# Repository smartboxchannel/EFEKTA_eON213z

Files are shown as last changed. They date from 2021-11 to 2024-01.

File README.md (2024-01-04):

# EFEKTA_eON213z

Телеграм чат DIY Devices - https://t.me/diy_devices

Продажа DIY Устройств - https://t.me/diydevmart

My new zigbee project. Wireless temperature and humidity mini sensor with electronic ink display 2.13 inches, low power consumption, compact size, enclosure with magnets. The device use SHTC3 sensors, chip CC2530, battery CR2477. Support in zigbee2mqtt, zha.

### It is forbidden to manufacture devices for commercial sale, only for personal use.

### You can buy a ready-made device by writing to the mail hello@efektalab.com

### Delivery is carried out worldwide.

## You can make your own pcb here - https://www.pcbway.com/setinvite.aspx?inviteid=550959

#### Sale: 

#### Video: https://youtu.be/5huTVfVpZgs

#### zigbee2mqtt.io/supported-devices: https://www.zigbee2mqtt.io/supported-devices/#s=efekta

#### Telegram DiyDev - https://t.me/diy_devices

More info at http://efektalab.com/eON213z

Chinese version - https://github.com/wzqvip/EFEKTA_eON213z/tree/Chinese_version

## V1_R1

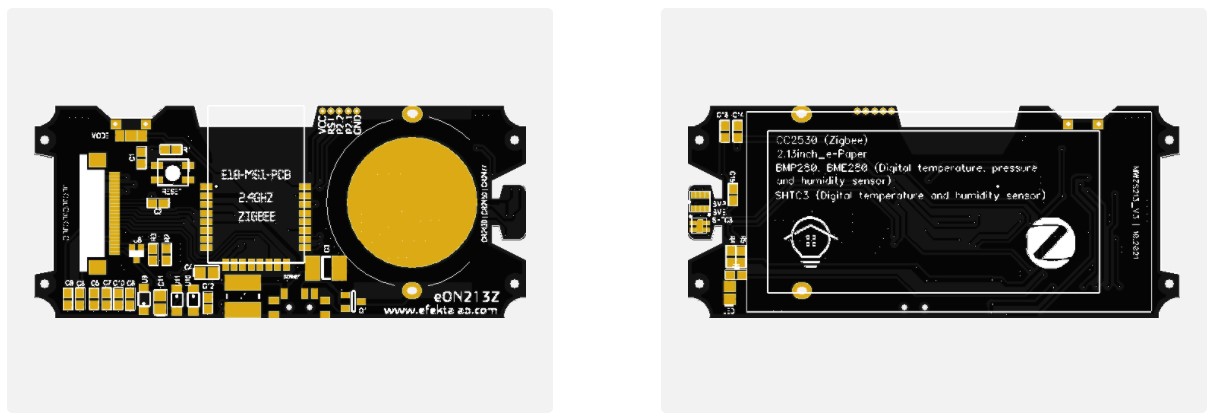
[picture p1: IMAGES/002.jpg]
 

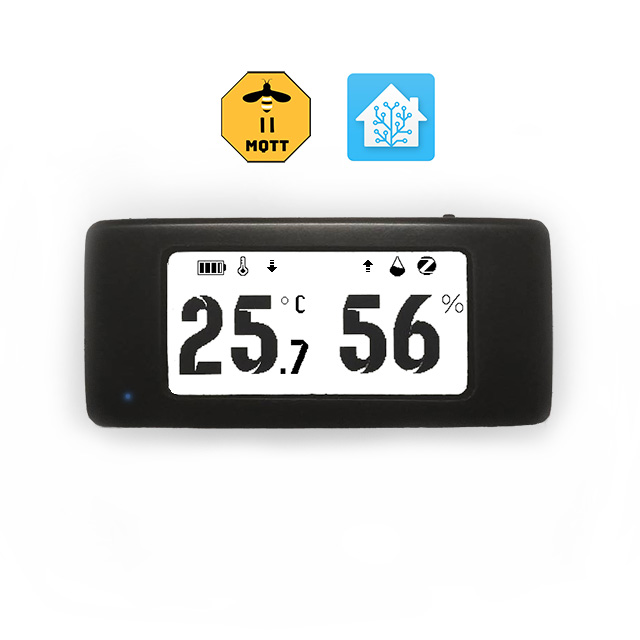
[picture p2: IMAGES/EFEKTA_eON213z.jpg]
Indoor climate sensor EFEKTA eON213 Zigbee
 

### How to flash the device

1. Download the Smart RF Flash Programmer V1 https://www.ti.com/tool/FLASH-PROGRAMMER

2. Open the application select the HEX firmware file

3. Connect the device with wires to CCDebugger, first erase the chip, then flash it.

---

### How to install IAR

https://github.com/ZigDevWiki/zigdevwiki.github.io/blob/main/docs/Begin/IAR_install.md

https://github.com/sigma7i/zigbee-wiki/wiki/zigbee-firmware-install (RU)

---

### How to join:
#### If device in FN(factory new) state:
##### one way
1. Open z2m, make sure that joining is prohibited
2. Insert the battery into the device
3. Click on the icon in z2m - allow joining (you have 180 seconds to add the device)
4. Go to the LOGS tab
5. Press the reset button on the device (the join procedure will begin, еhe device starts flashing the LED repeatedly)
6. Wait, in case of successfull join, device will flash led 5 times, if join failed, device will flash led 2 times

##### another way
1. Open z2m, make sure that joining is prohibited
2. Insert the battery into the device
3. Click on the icon in z2m - allow joining (you have 180 seconds to add the device)
4. Go to the LOGS tab
5. Press and hold button (1) for 2-3 seconds, until device start flashing the LED repeatedly
6. Wait, in case of successfull join, device will flash led 5 times, if join failed, device will flash led 2 times

#### If device in a network:
##### one way 
1. Hold button (1) for 10 seconds, this will reset device to FN(factory new) status 
2. Click on the icon in z2m - allow joining (you have 180 seconds to add the device)
3. Go to the LOGS tab
5. Press and hold button (1) for 2-3 seconds, until device start flashing the LED repeatedly
6. Wait, in case of successfull join, device will flash led 5 times, if join failed, device will flash led 2 times

##### another way
1.Find the device in the list of z2m devices and delete it by applying force remove
2. Click on the icon in z2m - allow joining (you have 180 seconds to add the device)
3. Go to the LOGS tab
4. Press the reset button on the device (the join procedure will begin, еhe device starts flashing the LED repeatedly)
5. Wait, in case of successfull join, device will flash led 5 times, if join failed, device will flash led 2 times

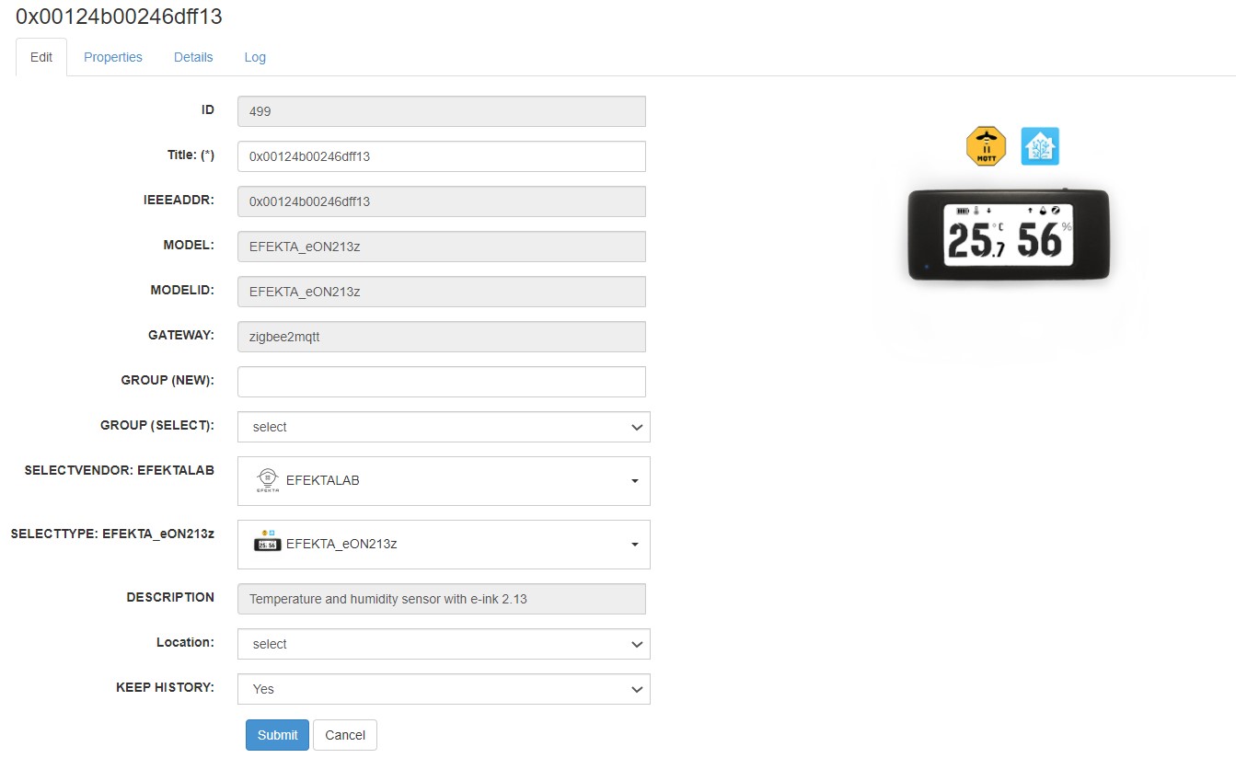
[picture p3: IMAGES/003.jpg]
Efekta THP_LR \ THP
 

### Troubleshooting

If a device does not connect to your coordinator, please try the following:

1. Power off all routers in your network.
2. Move the device near to your coordinator (about 1 meter).
or if you cannot disable routers (for example, internal switches), you may try the following:
2.1. Disconnect an external antenna from your coordinator.
2.2. Move a device to your coordinator closely (1-3 centimeters).
3. Power on, power on the device.
4. Restart your coordinator (for example, restart Zigbee2MQTT if you use it).

If the device has not fully passed the join

1. If the device is visible in the list of z2m devices, remove it by applying force remove
2. Restart your coordinator (for example, restart Zigbee2MQTT if you use it).
3. Click on the icon in z2m - allow joining (you have 180 seconds to add the device)
4. Go to the LOGS tab
5. Press and hold button (1) for 2-3 seconds, until device start flashing the LED repeatedly
6. Wait, in case of successfull join, device will flash led 5 times, if join failed, device will flash led 2 times

### Other checks

Please, ensure the following:

1. Your power source is OK (a battery has more than 3V). You can temporarily use an external power source for testings (for example, from a debugger).
2. The RF part of your E18 board works. You can upload another firmware to it and try to pair it with your coordinator. Or you may use another coordinator and build a separate Zigbee network for testing.
3. Your coordinator has free slots for direct connections.
4. You permit joining on your coordinator.
5. Your device did not join to other opened Zigbee network. When you press and hold the button, it should flash every 3-4 seconds. It means that the device in the joining state.

## Components (BOM):

CC2530 - https://ali.ski/x1m0vF (1 pc - $2.75)

CC2530 - https://ali.ski/mjth48 (10 pcs)

SHTC3 - https://ali.ski/yBYSsV (10 pcs - $15.76)

Waveshare 250x122 2,13 - https://ali.ski/D4eOVU (1pc - $13.3)

FPC FFC 0.5mm connector socket 24 pin - https://ali.ski/lCBot0 (1 p - $0.77)

Cell Holder CR2477 - https://ali.ski/CTUHOc (20 pcs - $5)

Micro Screws M1.4 3mm - https://ali.ski/gaFdO (100 pcs - $1)

Micro Screws M1.4 5mm - https://ali.ski/gaFdO (100 pcs - $1)

Micro SMD Tact Switch 2x4 2*4*3.5 - https://ali.ski/_D78Q (10 pcs - $1)

Neodymium magnet 15x3x3m - https://ali.ski/44p3R (10 pcs - $7)

Tantalum Capacitor 220UF 10V - https://ali.ski/Lx9iQd (10 pcs - $1,85)

Inductor Power Shielded Wirewound NR5040 5x5x4mm - https://ali.ski/iblu8q (50 pcs - $3)

Micro Button Tact Switch SMD 4Pin 3X4X2.5 - https://ali.ski/sGwFu (100 pcs - $1.7)

SMD Mini Toggle Slide Switch 7-Pin On/Off - https://ali.ski/xz9Yt (100 pcs - $3.2)

SI1308EDL - https://ali.ski/Q6Y12 (20 pcs - $5.3)
OR
Si1304BDL - https://ali.ski/938Klh (100 pcs - $15.5)

SMD Chip Multilayer Ceramic Capacitor 0603 1UF 25V - https://ali.ski/p3yr60 (100 pcs - $1.5)

SMD Chip Multilayer Ceramic Capacitor 0603 0.1UF 50V - https://ali.ski/p3yr60 (100 pcs - $1.5)

SMD Chip Multilayer Ceramic Capacitor 0805 4.7UF - https://ali.ski/iFXAc (100 pcs - $1.85)

MBR0530T1G - https://ali.ski/SJM7aK (100 pcs - $1.1)

SMD LED 0805 - https://ali.ski/wb6ZP (100 pcs - $2)

1% SMD resistor 0.47R 0603 - https://ali.ski/bX9HUg (100 pcs - $1.2)

1% SMD Resistor Kit Assorted Kit 1R-1M 0603 -  https://ali.ski/npItF (660 pcs - $1.45)

SUNLU PLA Carbon Fiber Premium 3D Printer Filament - https://ali.ski/bQkNR (1 pcs - $26.5)

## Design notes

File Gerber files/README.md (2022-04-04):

You can make your own pcb here - https://www.pcbway.com/setinvite.aspx?inviteid=550959

pcb 1mm - https://www.pcbway.com/project/shareproject/EFEKTA_eON213z_2ad692dc.html

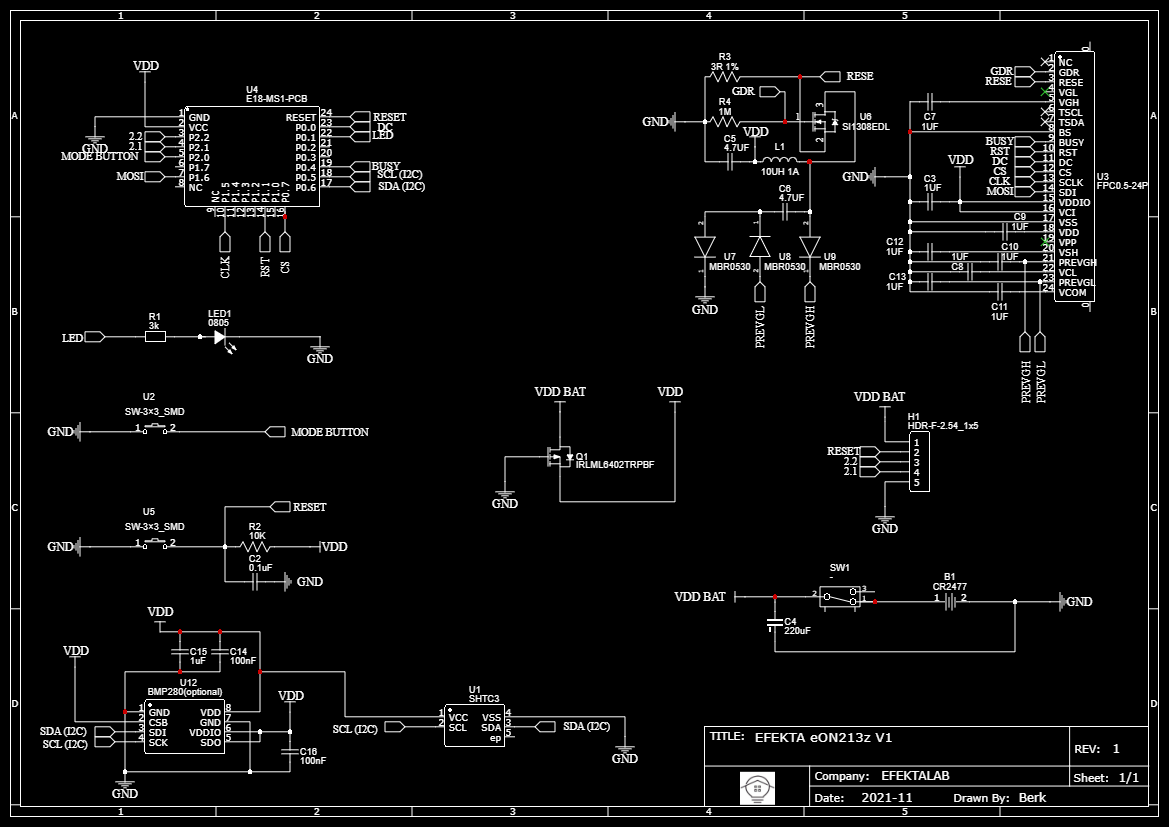
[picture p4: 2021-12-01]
SCHEME/Schematic_EFEKTA_eON213z.png

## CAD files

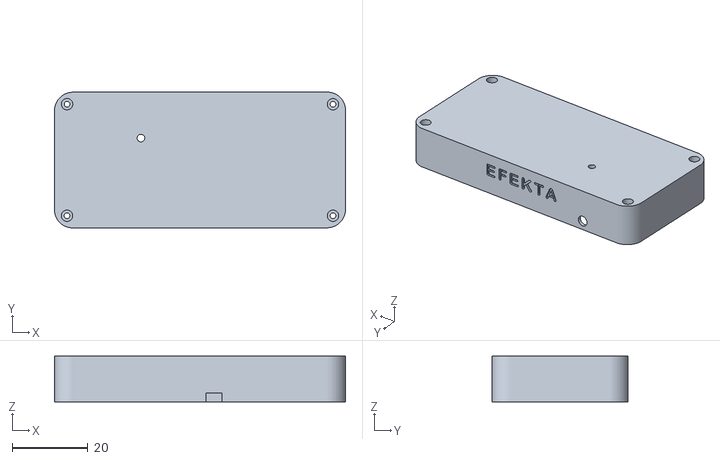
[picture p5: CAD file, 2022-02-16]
ENCLOSURE/thz2477_2.STL
76.6 x 35.7 x 12.1

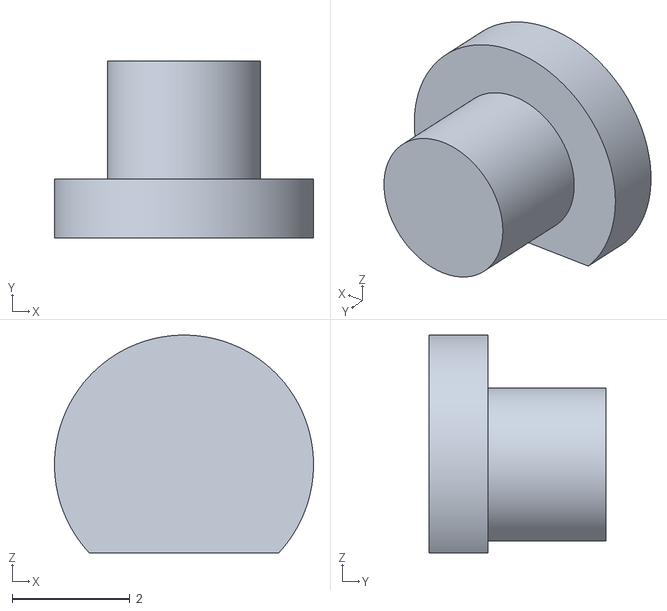
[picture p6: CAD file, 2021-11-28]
ENCLOSURE/thz2477_3.STL
4.40 x 3.00 x 3.70

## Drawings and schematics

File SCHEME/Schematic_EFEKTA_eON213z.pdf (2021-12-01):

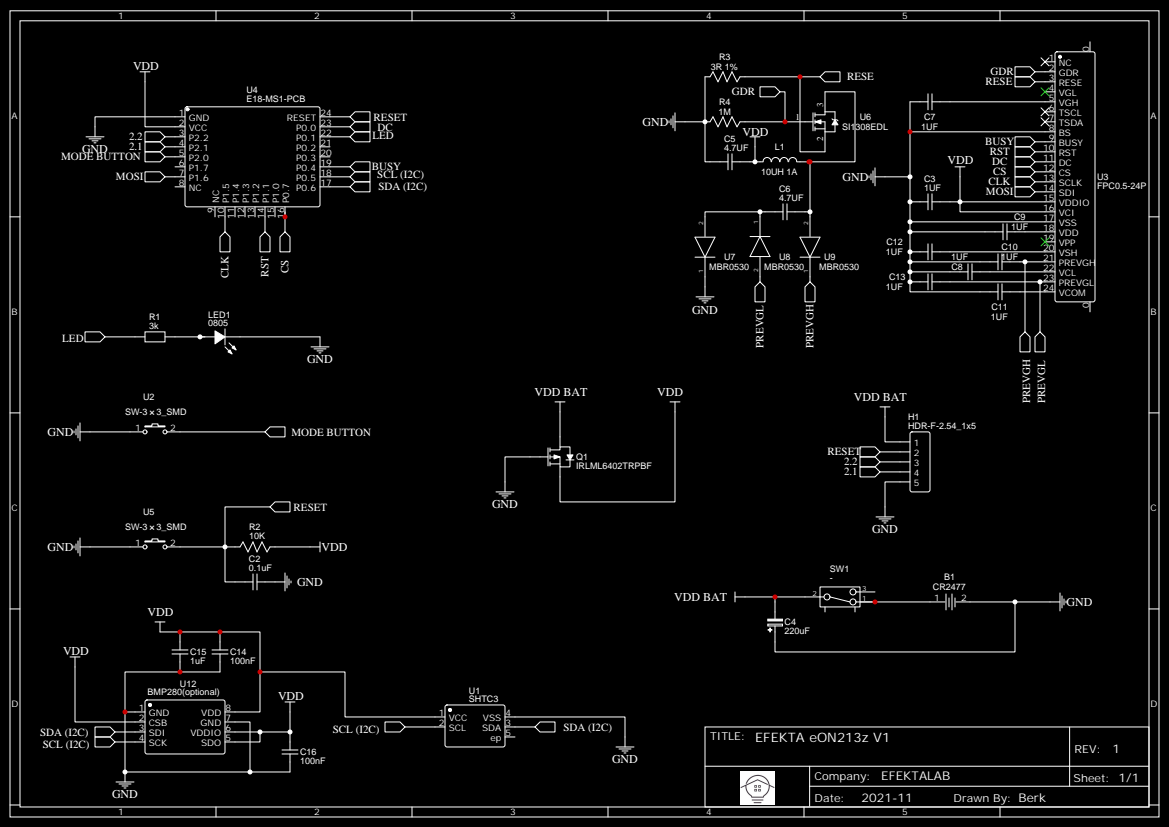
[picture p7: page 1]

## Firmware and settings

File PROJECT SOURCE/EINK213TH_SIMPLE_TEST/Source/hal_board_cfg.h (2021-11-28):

#ifndef HAL_BOARD_CFG_H
#define HAL_BOARD_CFG_H


/* ------------------------------------------------------------------------------------------------
 *                                           Includes
 * ------------------------------------------------------------------------------------------------
 */

#include "hal_mcu.h"
#include "hal_defs.h"
#include "hal_types.h"







/* ------------------------------------------------------------------------------------------------
 *                                          Clock Speed
 * ------------------------------------------------------------------------------------------------
 */

#define HAL_CPU_CLOCK_MHZ     32

/* 32 kHz clock source select in CLKCONCMD */
#if !defined (OSC32K_CRYSTAL_INSTALLED) || (defined (OSC32K_CRYSTAL_INSTALLED) && (OSC32K_CRYSTAL_INSTALLED == TRUE))
#define OSC_32KHZ  0x00 /* external 32 KHz xosc */
#else
#define OSC_32KHZ  0x80 /* internal 32 KHz rcosc */
#endif

#define HAL_CLOCK_STABLE() 

/* ------------------------------------------------------------------------------------------------
 *                                         Key Release detect support
 * ------------------------------------------------------------------------------------------------
 */
#define HAL_KEY_CODE_NOKEY 0xff


/* ------------------------------------------------------------------------------------------------
 *                                       LED Configuration
 * ------------------------------------------------------------------------------------------------
 */

// TODO: review all HAL_BOARD_CC2530EB_REV17 and replace with HAL_BOARD_CC2530RC
//       if applicable.
#define HAL_NUM_LEDS            0

#define HAL_LED_BLINK_DELAY()   st( { volatile uint32 i; for (i=0; i<0x5800; i++) { }; } )
#define ACTIVE_LOW        !
#define ACTIVE_HIGH       !!    /* double negation forces result to be '1' */

/* ------------------------------------------------------------------------------------------------
 *                         OSAL NV implemented by internal flash pages.
 * ------------------------------------------------------------------------------------------------
 */

// Flash is partitioned into 8 banks of 32 KB or 16 pages.
#define HAL_FLASH_PAGE_PER_BANK    16
// Flash is constructed of 128 pages of 2 KB.
#define HAL_FLASH_PAGE_SIZE        2048
#define HAL_FLASH_WORD_SIZE        4

// CODE banks get mapped into the XDATA range 8000-FFFF.
#define HAL_FLASH_PAGE_MAP         0x8000

// The last 16 bytes of the last available page are reserved for flash lock bits.
// NV page definitions must coincide with segment declaration in project *.xcl file.
#if defined NON_BANKED
#define HAL_FLASH_LOCK_BITS        16
#define HAL_NV_PAGE_END            30
#define HAL_NV_PAGE_CNT            2
#else
#define HAL_FLASH_LOCK_BITS        16
#define HAL_NV_PAGE_END            126
#define HAL_NV_PAGE_CNT            6
#endif

// Re-defining Z_EXTADDR_LEN here so as not to include a Z-Stack .h file.
#define HAL_FLASH_IEEE_SIZE        8
#define HAL_FLASH_IEEE_PAGE       (HAL_NV_PAGE_END+1)
#define HAL_FLASH_IEEE_OSET       (HAL_FLASH_PAGE_SIZE - HAL_FLASH_LOCK_BITS - HAL_FLASH_IEEE_SIZE)
#define HAL_INFOP_IEEE_OSET        0xC

#define HAL_FLASH_DEV_PRIVATE_KEY_OSET     0x7D2
#define HAL_FLASH_CA_PUBLIC_KEY_OSET       0x7BC
#define HAL_FLASH_IMPLICIT_CERT_OSET       0x78C

#define HAL_NV_PAGE_BEG           (HAL_NV_PAGE_END-HAL_NV_PAGE_CNT+1)
// Used by DMA macros to shift 1 to create a mask for DMA registers.
#define HAL_NV_DMA_CH              0
#define HAL_DMA_CH_RX              3
#define HAL_DMA_CH_TX              4

#define HAL_NV_DMA_GET_DESC()      HAL_DMA_GET_DESC0()
#define HAL_NV_DMA_SET_ADDR(a)     HAL_DMA_SET_ADDR_DESC0((a))

/* ------------------------------------------------------------------------------------------------
 *  Serial Boot Loader: reserving the first 4 pages of flash and other memory in cc2530-sb.xcl.
 * ------------------------------------------------------------------------------------------------
 */

#define HAL_SB_IMG_ADDR       0x2000
#define HAL_SB_CRC_ADDR       0x2090
// Size of internal flash less 4 pages for boot loader, 6 pages for NV, & 1 page for lock bits.
#define HAL_SB_IMG_SIZE      (0x40000 - 0x2000 - 0x3000 - 0x0800)

/* ------------------------------------------------------------------------------------------------
 *                                            Macros
 * ------------------------------------------------------------------------------------------------
 */

/* ----------- RF-frontend Connection Initialization ---------- */
#if defined HAL_PA_LNA || defined HAL_PA_LNA_CC2590
extern void MAC_RfFrontendSetup(void);
#define HAL_BOARD_RF_FRONTEND_SETUP() MAC_RfFrontendSetup()
#else
#define HAL_BOARD_RF_FRONTEND_SETUP()
#endif
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

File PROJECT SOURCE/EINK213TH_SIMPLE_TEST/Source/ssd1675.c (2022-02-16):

#include <stdlib.h>


#include "ssd1675.h"
#include "spi.h" // HalLcd_HW_Control(), HalLcd_HW_Write()
#include "imagedata.h"
#include "epdpaint.h"
#include "utils.h"

#define HAL_LCD_BUSY BNAME(HAL_LCD_BUSY_PORT, HAL_LCD_BUSY_PIN)

void DelayMs(unsigned int delaytime);

unsigned long epd_width = EPD_WIDTH;
unsigned long epd_height = EPD_HEIGHT;


void EpdInitFull(void) {  
  EpdReset();
  
  WaitUntilIdle();
  EpdSendCommand(SW_RESET);  //SWRESET
  WaitUntilIdle();
  
  EpdSendCommand(0x74); //set analog block control
  EpdSendData(0x54);
  EpdSendCommand(0x7E); //set digital block control
  EpdSendData(0x3B);
  
  EpdSendCommand(DRIVER_OUTPUT_CONTROL); //Driver output control
  EpdSendData(0xF9);
  EpdSendData(0x00);
  EpdSendData(0x00);
  
  EpdSendCommand(DATA_ENTRY_MODE_SETTING); //data entry mode
  EpdSendData(0x03);

  EpdSetMemoryArea(0, 0, epd_width - 1, epd_height - 1);
   
  EpdSendCommand(BORDER_WAVEFORM_CONTROL);
  EpdSendData(0x03);
  
  EpdSendCommand(WRITE_VCOM_REGISTER); //VCOM Voltage
  EpdSendData(0x55); //
  
  EpdSendCommand(GATE_VOLTAGE_CONTROL);
  EpdSendData(lut_full_update[70]);
  
  EpdSendCommand(SOURCE_VOLTAGE_CONTROL); //
  EpdSendData(lut_full_update[71]);
  EpdSendData(lut_full_update[72]);
  EpdSendData(lut_full_update[73]);
  
  EpdSendCommand(SET_DUMMY_LINE_PERIOD);     //Dummy Line
  EpdSendData(lut_full_update[74]);
  EpdSendCommand(SET_GATE_TIME);     //Gate time
  EpdSendData(lut_full_update[75]);
  
  EpdSetMemoryPointer(0, 0);
  
  EpdSetLutFull(lut_full_update);
}


void EpdInitPartial(void) { 
    EpdReset();

    EpdSendCommand(WRITE_VCOM_REGISTER);     //VCOM Voltage
    EpdSendData(0x26);

    WaitUntilIdle();
        
    EpdSetLut(lut_partial_update);
}


void EpdSendCommand(unsigned char command) {
    HalLcd_HW_Control(command);
}


void EpdSendData(unsigned char data) {
    HalLcd_HW_Write(data);
}


void WaitUntilIdle(void) {
   while (1) {     //LOW: idle, HIGH: busy
    if (HAL_LCD_BUSY == 0)
      break;
    DelayMs(20);
  }
}



void DelayMs(unsigned int delaytime) {
  while(delaytime--)
  {
    uint16 microSecs = 1000;
    while(microSecs--)
    {
      asm("nop"); asm("nop"); asm("nop"); asm("nop"); asm("nop"); asm("nop");
    }
  }
}

const unsigned char lut_full_update[]= {
    0x80,0x60,0x40,0x00,0x00,0x00,0x00,             //LUT0: BB:     VS 0 ~7
    0x10,0x60,0x20,0x00,0x00,0x00,0x00,             //LUT1: BW:     VS 0 ~7
    0x80,0x60,0x40,0x00,0x00,0x00,0x00,             //LUT2: WB:     VS 0 ~7
    0x10,0x60,0x20,0x00,0x00,0x00,0x00,             //LUT3: WW:     VS 0 ~7
    0x00,0x00,0x00,0x00,0x00,0x00,0x00,             //LUT4: VCOM:   VS 0 ~7

    0x03,0x03,0x00,0x00,0x02,                       // TP0 A~D RP0
    0x09,0x09,0x00,0x00,0x02,                       // TP1 A~D RP1
    0x03,0x03,0x00,0x00,0x02,                       // TP2 A~D RP2
    0x00,0x00,0x00,0x00,0x00,                       // TP3 A~D RP3
    0x00,0x00,0x00,0x00,0x00,                       // TP4 A~D RP4
    0x00,0x00,0x00,0x00,0x00,                       // TP5 A~D RP5
    0x00,0x00,0x00,0x00,0x00,                       // TP6 A~D RP6

    0x15,0x41,0xA8,0x32,0x30,0x0A,
};

const unsigned char lut_partial_update[]= { //20 bytes
    0x00,0x00,0x00,0x00,0x00,0x00,0x00,             //LUT0: BB:     VS 0 ~7
    0x80,0x00,0x00,0x00,0x00,0x00,0x00,             //LUT1: BW:     VS 0 ~7
    0x40,0x00,0x00,0x00,0x00,0x00,0x00,             //LUT2: WB:     VS 0 ~7
    0x00,0x00,0x00,0x00,0x00,0x00,0x00,             //LUT3: WW:     VS 0 ~7
    0x00,0x00,0x00,0x00,0x00,0x00,0x00,             //LUT4: VCOM:   VS 0 ~7

    0x0A,0x00,0x00,0x00,0x00,                       // TP0 A~D RP0
    0x00,0x00,0x00,0x00,0x00,                       // TP1 A~D RP1
    0x00,0x00,0x00,0x00,0x00,                       // TP2 A~D RP2
    0x00,0x00,0x00,0x00,0x00,                       // TP3 A~D RP3
    0x00,0x00,0x00,0x00,0x00,                       // TP4 A~D RP4
    0x00,0x00,0x00,0x00,0x00,                       // TP5 A~D RP5
    0x00,0x00,0x00,0x00,0x00,                       // TP6 A~D RP6

    0x15,0x41,0xA8,0x32,0x30,0x0A,
};


void EpdSetLutFull(const unsigned char *lut) {
  unsigned char count;
  EpdSendCommand(WRITE_LUT_REGISTER);
  for(count = 0; count < 70; count++) {
    EpdSendData(lut[count]);
  }
/*
  EpdSendCommand(SET_RAM_X_ADDRESS_COUNTER);   // set RAM x address count to 0;
  EpdSendData(0x00);
  EpdSendCommand(SET_RAM_Y_ADDRESS_COUNTER);   // set RAM y address count to 0X127;
  EpdSendData(0xF9);
  EpdSendData(0x00);
*/
  
  WaitUntilIdle();
}  

void EpdSetLut(const unsigned char *lut) {       
  unsigned char count;
  EpdSendCommand(WRITE_LUT_REGISTER);
  for(count = 0; count < 70; count++) {
    EpdSendData(lut[count]);
  }
  
  EpdSendCommand(OTP_SELECTION_CONTROL_1);
  EpdSendData(0x00);
  EpdSendData(0x00);
  EpdSendData(0x00);
  EpdSendData(0x00);
  EpdSendData(0x40);
  EpdSendData(0x00);
  EpdSendData(0x00);

  EpdSendCommand(DISPLAY_UPDATE_CONTROL_2);
  EpdSendData(0xC0);

  EpdSendCommand(MASTER_ACTIVATION);
  
  WaitUntilIdle();
  
  EpdSendCommand(BORDER_WAVEFORM_CONTROL); //BorderWavefrom
  EpdSendData(0x01);
}


void EpdSetFrameMemoryXY(const unsigned char* image_buffer, int x, int y, int image_width, int image_height) { 
    int x_end;
    int y_end;    

    if (
        image_buffer == NULL ||
        x < 0 || image_width < 0 ||
        y < 0 || image_height < 0
    ) {
        return;
    }
    // x point must be the multiple of 8 or the last 3 bits will be ignored 
    x &= 0xF8;
    image_width &= 0xF8;
    if (x + image_width >= epd_width) {
        x_end = epd_width - 1;
    } else {
        x_end = x + image_width - 1;
    }
    if (y + image_height >= epd_height) {
        y_end = epd_height - 1;
    } else {
        y_end = y + image_height - 1;
    }
    
    EpdSetMemoryArea(x, y, x_end, y_end);
    EpdSetMemoryPointer(x, y);
    
    
    EpdSendCommand(WRITE_RAM);
    // send the image data
    for (int j = 0; j < y_end - y + 1; j++) {
        for (int i = 0; i < (x_end - x + 1) / 8; i++) {
            EpdSendData(image_buffer[i + j * (image_width / 8)]);
        }
    }
}

void EpdSetFrameMemory(const unsigned char* image_buffer) {
    EpdSetMemoryArea(0, 0, epd_width - 1, epd_height - 1);
    EpdSetMemoryPointer(0, 0);
    EpdSendCommand(WRITE_RAM);
    /* send the image data */
    for (int i = 0; i < epd_width / 8 * epd_height; i++) {
        EpdSendData((uint8)(image_buffer[i]));
    }
}

void EpdSetFrameMemoryBase(const unsigned char* image_buffer) {
  EpdSetMemoryArea(0, 0, epd_width - 1, epd_height - 1);
  EpdSetMemoryPointer(0, 0);
  EpdSendCommand(WRITE_RAM);
  /* send the image data */
  for (int i = 0; i < epd_width / 8 * epd_height; i++) {
    EpdSendData((uint8)(image_buffer[i]));
  }
  EpdSendCommand(WRITE_RAM2);
  /* send the image data */
  for (int i = 0; i < epd_width / 8 * epd_height; i++) {
    EpdSendData((uint8)(image_buffer[i]));
  }
}
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
